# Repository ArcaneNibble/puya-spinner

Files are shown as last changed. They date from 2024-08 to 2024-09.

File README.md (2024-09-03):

# PY32 fidget spinner demo

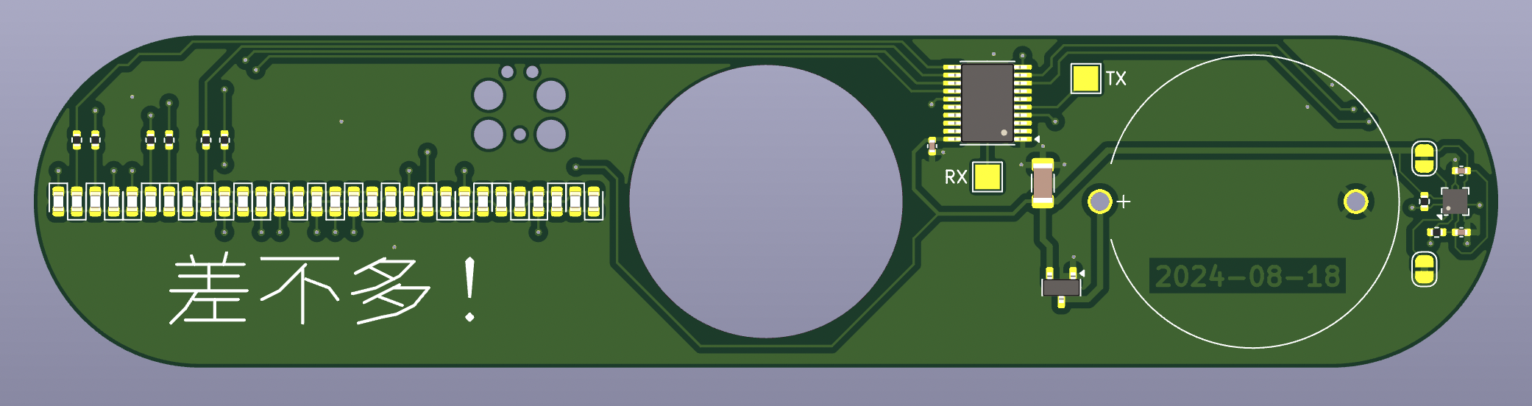
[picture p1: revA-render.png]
3d render of board


This is a quick-and-dirty demo of _just_ how cheap embedded compute can get nowadays &mdash; approximately USD$6 for an *assembled* board with a 32-bit Cortex-M0.

In order to actually make good use of this available compute, the idea was to build a modern (i.e. state-space) control theory estimator to determine the orientation of the fidget spinner from accelerometer data, rather than more traditional approaches involving hall effect sensors.

## Status

Revision A was ordered from JLCPCB, and all of the essential components work.

The state estimator has yet to be written, as the author is aphantasic and not much of a shape rotator (and thus struggling with writing out the necessary "physical world" equations).

## Main components

* PY32F002AL15 (MCU)
* SC7A20 (accelerometer)
* CR2032 battery
* 30 charlieplexed LEDs

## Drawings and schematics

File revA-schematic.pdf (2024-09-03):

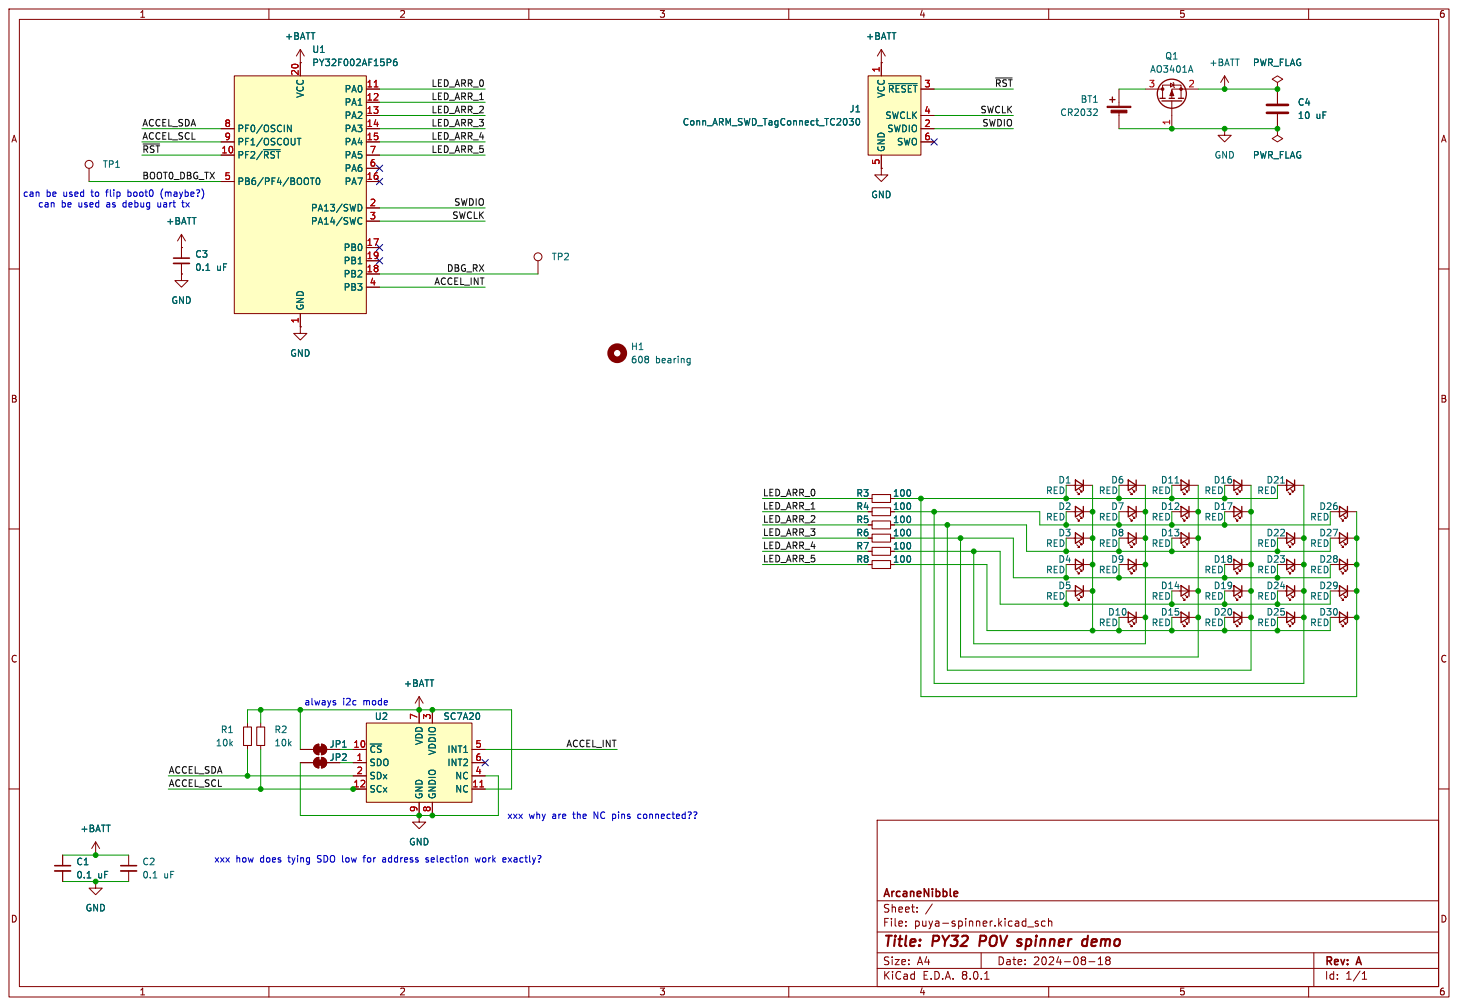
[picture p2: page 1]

1 PF2/~{RST} 10 PA0 11 PA1 12 PA2 13 PA3 14 PA4 15 PA7 16 PB0 17 PB2 18 PB1 19 PA13/SWD 2 VCC 20 PA14/SWC 3 PB3 4 PB6/PF4/BOOT0 5 PA6 6 PA5 7 PF0/OSCIN 8 PF1/OSCOUT 9 U1PY32F002AF15P6 +BATT D29 RED

1 PF2/~{RST} 10 PA0 11 PA1 12 PA2 13 PA3 14 PA4 15 PA7 16 PB0 17 PB2 18 PB1 19 PA13/SWD 2 VCC 20 PA14/SWC 3 PB3 4 PB6/PF4/BOOT0 5 PA6 6 PA5 7 PF0/OSCIN 8 PF1/OSCOUT 9 GND

1 SWDIO 2 ~{RESET}3 SWCLK 4 GND

xxx why are the NC pins connected??

File: puya-spinner.kicad_sch Sheet: / ArcaneNibble GND

Id: 1/1 Title: PY32 POV spinner demo

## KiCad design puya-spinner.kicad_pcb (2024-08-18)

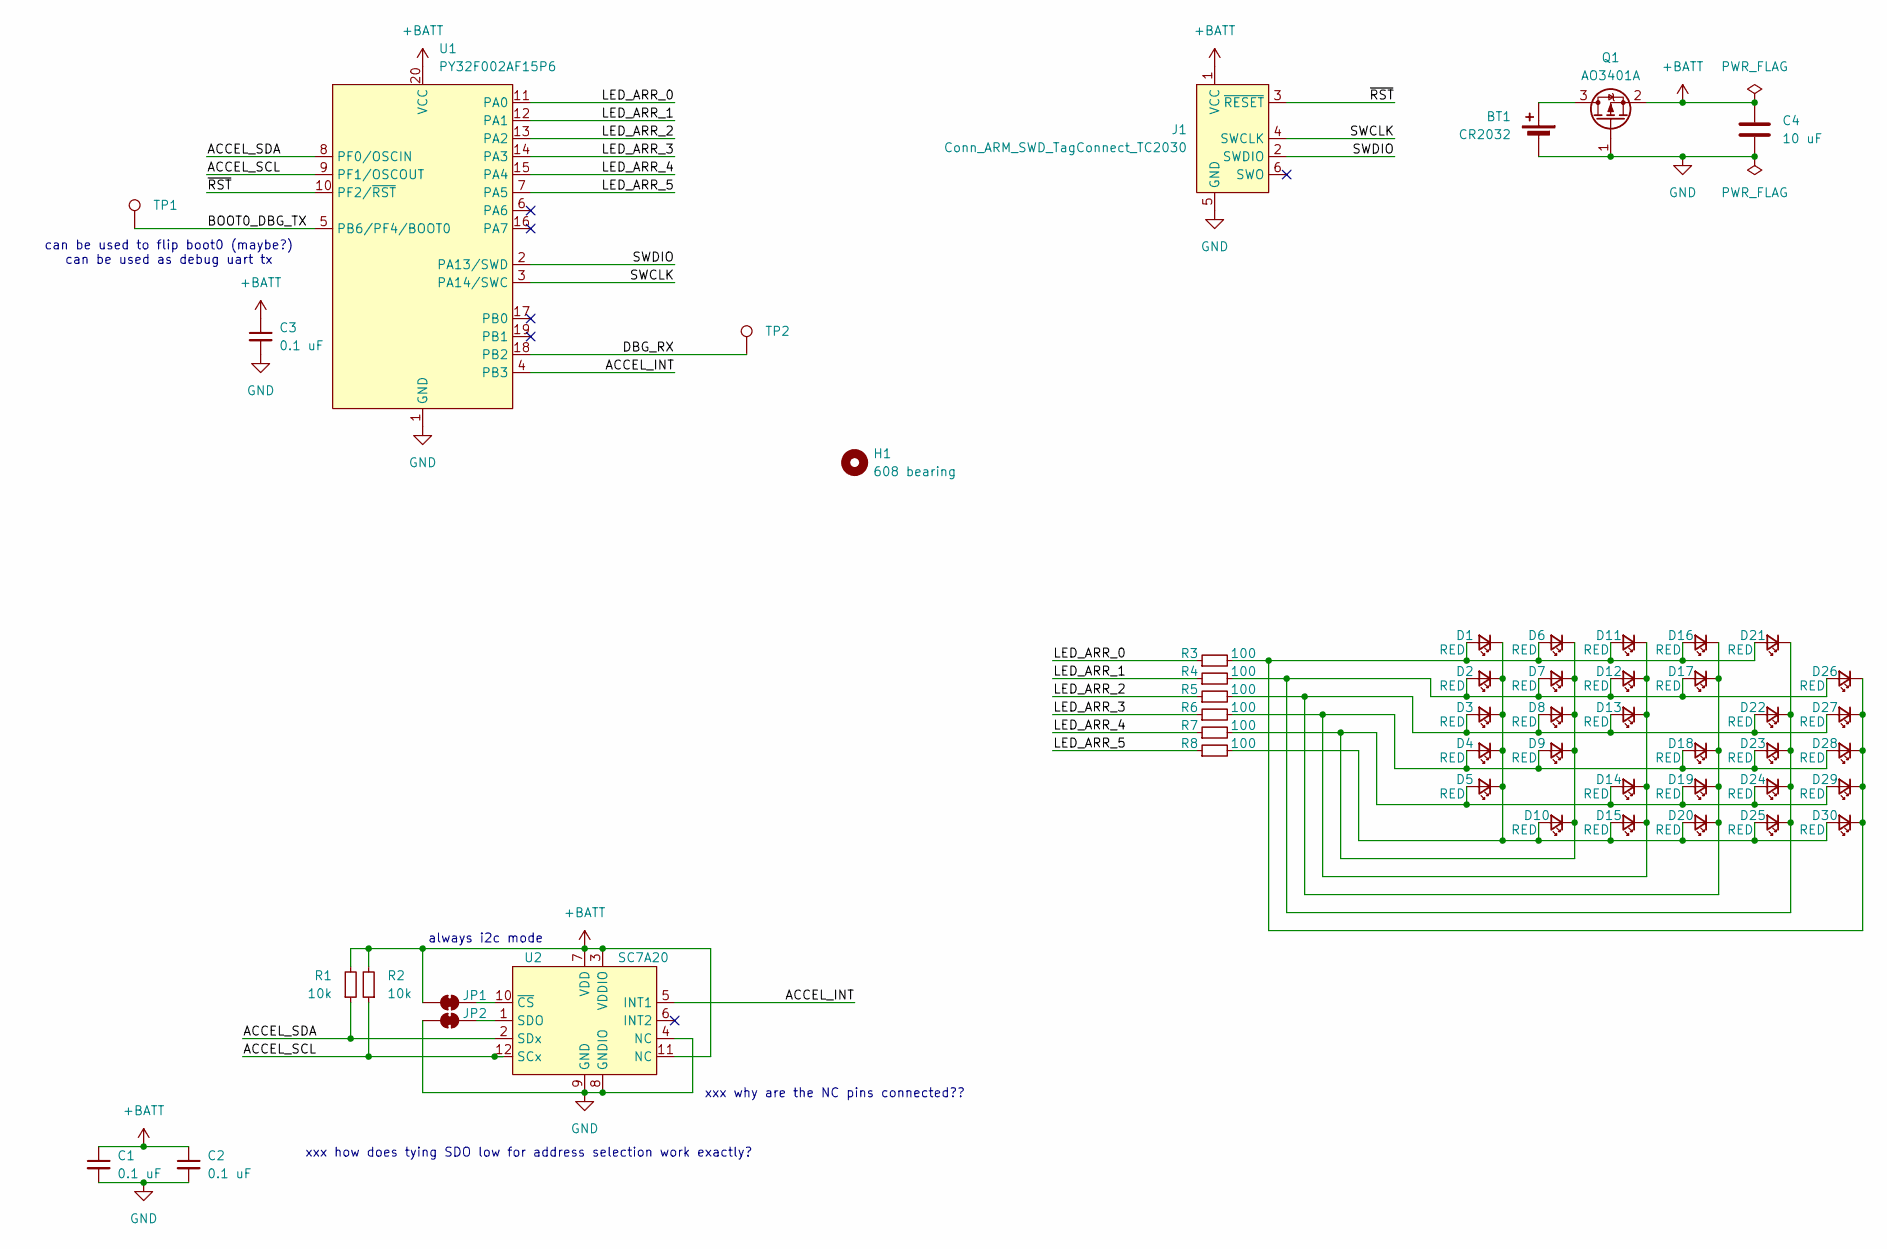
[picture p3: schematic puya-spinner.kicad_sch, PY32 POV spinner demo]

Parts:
BT1: CR2032; Battery_MYOUNG_BS-07-A1BJ001_CR2032; LCSC C2979167
C1, C2, C3: 0.1 uF; C_0402_1005Metric; LCSC C1525
C4: 10 uF; C_1206_3216Metric; LCSC C13585
D1, D2, D3, D4, D5, D6, D7, D8, D9, D10, D11, D12, D13, D14, D15, D16, D17, D18, D19, D20, D21, D22, D23, D24, D25, D26, D27, D28, D29, D30: RED; LED_0603_1608Metric; LCSC C2286
H1: 608 bearing; fixme_608_bearing
J1: Conn_ARM_SWD_TagConnect_TC2030; Tag-Connect_TC2030-IDC-FP_2x03_P1.27mm_Vertical
JP1, JP2: SolderJumper_2_Bridged; SolderJumper-2_P1.3mm_Bridged_RoundedPad1.0x1.5mm
Q1: AO3401A; SOT-23; LCSC C15127
R1, R2: 10k; R_0402_1005Metric; LCSC C25744
R3, R4, R5, R6, R7, R8: 100; R_0402_1005Metric; LCSC C25076
TP1, TP2: TestPoint; TestPoint_Pad_2.0x2.0mm
U1: PY32F002AF15P6; TSSOP-20_4.4x6.5mm_P0.65mm; LCSC C5292059
U2: SC7A20; LGA-12_2x2mm_P0.5mm; LCSC C5126709

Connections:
+BATT: C1.1, C2.1, C3.1, C4.1, J1.1 (VCC), JP1.1 (A), Q1.2 (S), R1.2, R2.2, U1.20 (VCC), U2.3 (VDDIO), U2.7 (VDD), U2.11 (NC)
/ACCEL_INT: U1.4 (PB3), U2.5 (INT1)
/ACCEL_SCL: R2.1, U1.9 (PF1/OSCOUT), U2.12 (SCx)
/ACCEL_SDA: R1.1, U1.8 (PF0/OSCIN), U2.2 (SDx)
/BOOT0_DBG_TX: TP1.1, U1.5 (PB6/PF4/BOOT0)
/DBG_RX: TP2.1, U1.18 (PB2)
/LED_ARR_0: R3.1, U1.11 (PA0)
/LED_ARR_1: R4.1, U1.12 (PA1)
/LED_ARR_2: R5.1, U1.13 (PA2)
/LED_ARR_3: R6.1, U1.14 (PA3)
/LED_ARR_4: R7.1, U1.15 (PA4)
/LED_ARR_5: R8.1, U1.7 (PA5)
/SWCLK: J1.4 (SWCLK), U1.3 (PA14/SWC)
/SWDIO: J1.2 (SWDIO), U1.2 (PA13/SWD)
/~RST: J1.3 (~RESET), U1.10 (PF2/~RST)
GND: BT1.2 (-), C1.2, C2.2, C3.2, C4.2, J1.5 (GND), JP2.1 (A), Q1.1 (G), U1.1 (GND), U2.4 (NC), U2.8 (GNDIO), U2.9 (GND)
unnamed: BT1.1 (+), Q1.3 (D)
unnamed: D1.2 (A), D6.2 (A), D11.2 (A), D16.2 (A), D21.2 (A), D26.1 (K), D27.1 (K), D28.1 (K), D29.1 (K), D30.1 (K), R3.2
unnamed: D1.1 (K), D2.1 (K), D3.1 (K), D4.1 (K), D5.1 (K), D10.2 (A), D15.2 (A), D20.2 (A), D25.2 (A), D30.2 (A), R8.2
unnamed: D5.2 (A), D6.1 (K), D7.1 (K), D8.1 (K), D9.1 (K), D10.1 (K), D14.2 (A), D19.2 (A), D24.2 (A), D29.2 (A), R7.2
unnamed: D4.2 (A), D9.2 (A), D11.1 (K), D12.1 (K), D13.1 (K), D14.1 (K), D15.1 (K), D18.2 (A), D23.2 (A), D28.2 (A), R6.2
unnamed: D2.2 (A), D7.2 (A), D12.2 (A), D17.2 (A), D21.1 (K), D22.1 (K), D23.1 (K), D24.1 (K), D25.1 (K), D26.2 (A), R4.2
unnamed: D3.2 (A), D8.2 (A), D13.2 (A), D16.1 (K), D17.1 (K), D18.1 (K), D19.1 (K), D20.1 (K), D22.2 (A), D27.2 (A), R5.2
unnamed: JP1.2 (B), U2.10 (~CS)
unnamed: JP2.2 (B), U2.1 (SDO)

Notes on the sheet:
always i2c mode
can be used to flip boot0 (maybe?) can be used as debug uart tx
xxx how does tying SDO low for address selection work exactly?
xxx why are the NC pins connected??

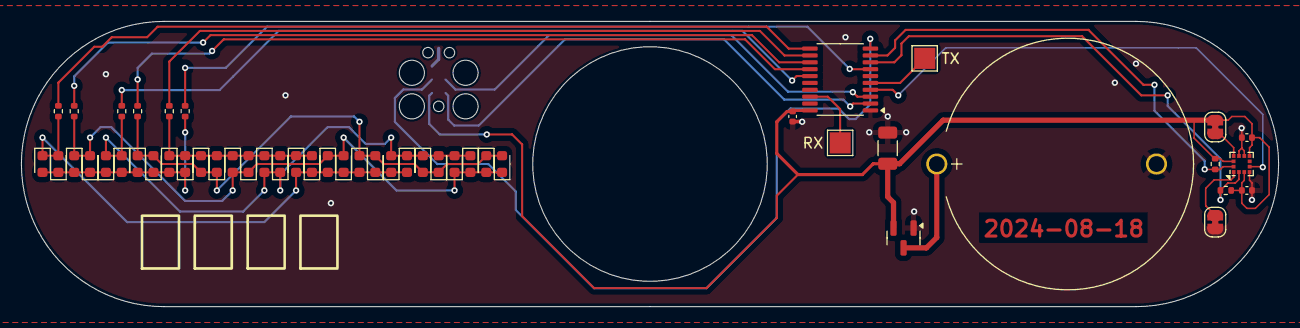
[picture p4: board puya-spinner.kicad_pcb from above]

Board: 2 copper layers, 119.0 x 27.0 mm, 52 parts (1 on the bottom side), 25 nets.

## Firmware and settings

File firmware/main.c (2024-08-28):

#include "registers.h"
#include "accel.h"
#include "led.h"
#include <math.h>

uint8_t debug_accel_whoami;
uint8_t debug_accel_ctrl_readback[6];
#define DEBUG_BUF_NENTS     1200
int16_t debug_accel_buffer[DEBUG_BUF_NENTS];
uint32_t debug_accel_buffer_idx;

void main() {
    /// 24 MHz HSI
    RCC_ICSCR = RCC_ICSCR & 0xffff0000 | (4 << 13) | CAL_HSI_24M;

    /// GPIO power on
    RCC_IOPENR = 0b100011;

    /// I2C setup
    RCC_APBENR1 |= (1 << 21);
    // 24 MHz system clock
    I2C_CR2 = 24;
    // 400 kHz I2C
    I2C_CCR = (1 << 15) | 20;
    I2C_TRISE = 8;
    // enable
    I2C_CR1 = 1;
    // gpio
    GPIOF_OTYPER = 0b11;
    GPIOF_OSPEEDR = 0b1010;
    GPIOF_AFRL = 0xcc;
    GPIOF_MODER = (GPIOF_MODER & ~0b1111) | 0b1010;

    /// Accel setup
    debug_accel_whoami = accel_read_reg(0x0f);
    accel_write_reg(0x20, 0b01110111);
    accel_write_reg(0x21, 0b00000000);
    accel_write_reg(0x22, 0b00010000);
    accel_write_reg(0x23, 0b00001000);
    accel_write_reg(0x24, 0b00000000);
    accel_write_reg(0x25, 0b00000000);
    accel_read_multi_reg(0x20, 6, debug_accel_ctrl_readback);

    /// xxx dummy data
    for (int i = 0; i < NUM_SECTORS; i++) {
        led_data[i] = (1 << (i % (NUM_LEDS + 1))) - 1;
    }

    /// systick setup, 24 kHz = 30 LEDs * 400 Hz * 2x doubling
    SYST_CVR = 0;
    SYST_RVR = 999;
    SYST_CSR = 0b111;

    /// PB3 = accel interrupt
    GPIOB_MODER &= ~(0b11 << 6);
    EXTI_EXTICR1 = 0b01 << 24;
    EXTI_RTSR = 1 << 3;
    EXTI_IMR |= 1 << 3;
    NVIC_IPR1 = 0xc0 << 16;     // lower prio than led

    // initial read to make sure interrupt pin is cleared
    while (!(GPIOB_IDR & (1 << 3))) {}
    uint8_t dummy_accel_buf[7];
    accel_read_multi_reg(0x27, 7, dummy_accel_buf);

    /// final interrupt enable
    NVIC_ISER = 1 << 6;
    
    while (1)
        asm volatile("wfi");
}

void EXTI2_3_IRQHandler() {
    EXTI_PR = 1 << 3;
    uint8_t accel_buf[7];
    accel_read_multi_reg(0x27, 7, accel_buf);

    int16_t x = accel_buf[1] | (accel_buf[2] << 8);
    int16_t y = accel_buf[3] | (accel_buf[4] << 8);
    int16_t z = accel_buf[5] | (accel_buf[6] << 8);

    debug_accel_buffer[debug_accel_buffer_idx++] = x;
    debug_accel_buffer[debug_accel_buffer_idx++] = y;
    debug_accel_buffer[debug_accel_buffer_idx++] = z;
    if (debug_accel_buffer_idx == DEBUG_BUF_NENTS)
        debug_accel_buffer_idx = 0;

    // maths!
    float angle = atan2f(-y, x);
    float led_sector_f = angle * ((float)(NUM_SECTORS / 2) / (float)(M_PI));
    int led_sector = floorf(led_sector_f);
    if (led_sector < 0)
        led_sector += NUM_SECTORS;
    led_current_sector = led_sector;
}

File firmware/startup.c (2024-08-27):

extern unsigned int _etext;
extern unsigned int _data;
extern unsigned int _edata;
extern unsigned int _bss;
extern unsigned int _ebss;
extern char _eusrstack;

extern void (*__preinit_array_start []) ();
extern void (*__preinit_array_end []) ();
extern void (*__init_array_start []) ();
extern void (*__init_array_end []) ();
extern void (*__fini_array_start []) ();
extern void (*__fini_array_end []) ();

extern void main();
void _start() {
    unsigned int *src, *dst;

    // copy initialized data
    src = &_etext;
    dst = &_data;
    while (dst < &_edata)
        *dst++ = *src++;
    
    // clear bss
    dst = &_bss;
    while (dst < &_ebss)
        *dst++ = 0;
    
    // init functions
    void (**fn)();

    fn = __preinit_array_start;
    while (fn != __preinit_array_end)
        (*fn++)();
    fn = __init_array_start;
    while (fn != __init_array_end)
        (*fn++)();

    // finally invoke main
    main();

    // fini functions
    fn = __fini_array_start;
    while (fn != __fini_array_end)
        (*fn++)();

    // hang
    while (1) {}
}

#define DUMMY __attribute__ ((weak, alias ("__irq_handler_dummy")))
void __irq_handler_dummy()
{
  	while (1);
}

DUMMY void NMI_Handler();
DUMMY void HardFault_Handler();
DUMMY void SVC_Handler();
DUMMY void PendSV_Handler();
DUMMY void SysTick_Handler();
DUMMY void WWDG_IRQHandler();
DUMMY void PVD_IRQHandler();
DUMMY void RTC_IRQHandler();
DUMMY void FLASH_IRQHandler();
DUMMY void RCC_IRQHandler();
DUMMY void EXTI0_1_IRQHandler();
DUMMY void EXTI2_3_IRQHandler();
DUMMY void EXTI4_15_IRQHandler();
DUMMY void DMA1_Channel1_IRQHandler();
DUMMY void DMA1_Channel2_3_IRQHandler();
DUMMY void ADC_COMP_IRQHandler();
DUMMY void TIM1_BRK_UP_TRG_COM_IRQHandler();
DUMMY void TIM1_CC_IRQHandler();
DUMMY void TIM3_IRQHandler();
DUMMY void LPTIM1_IRQHandler();
DUMMY void TIM14_IRQHandler();
DUMMY void TIM16_IRQHandler();
DUMMY void TIM17_IRQHandler();
DUMMY void I2C1_IRQHandler();
DUMMY void SPI1_IRQHandler();
DUMMY void SPI2_IRQHandler();
DUMMY void USART1_IRQHandler();
DUMMY void USART2_IRQHandler();
DUMMY void LED_IRQHandler();

__attribute__ ((used, section(".vectors")))
void (* const __vectors[])() =
{
    (void (*const)())&_eusrstack,
    _start,
    NMI_Handler,
    HardFault_Handler,

    0, 0, 0, 0,

    0, 0, 0,
    SVC_Handler,

    0, 0,
    PendSV_Handler,
    SysTick_Handler,

    WWDG_IRQHandler,
    PVD_IRQHandler,
    RTC_IRQHandler,
    FLASH_IRQHandler,

    RCC_IRQHandler,
    EXTI0_1_IRQHandler,
    EXTI2_3_IRQHandler,
    EXTI4_15_IRQHandler,

    0,
    DMA1_Channel1_IRQHandler,
    DMA1_Channel2_3_IRQHandler,
    0,

    ADC_COMP_IRQHandler,
    TIM1_BRK_UP_TRG_COM_IRQHandler,
    TIM1_CC_IRQHandler,
    0,

    TIM3_IRQHandler,
    LPTIM1_IRQHandler,
    0,
    TIM14_IRQHandler,

    0,
    TIM16_IRQHandler,
    TIM17_IRQHandler,
    I2C1_IRQHandler,

    0,
    SPI1_IRQHandler,
    SPI2_IRQHandler,
    USART1_IRQHandler,
    
    USART2_IRQHandler,
    0,
    LED_IRQHandler,
    0,
};

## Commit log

2024-07-09 add custom parts
    [puya-spinner.kicad_sch]
2024-07-09 initial sch
    [puya-spinner.kicad_sch]
2024-07-10 assign most parts
    [puya-spinner.kicad_sch]
2024-07-10 add power flags; fix interrupt pin
    [puya-spinner.kicad_sch]
2024-07-10 add battery holder footprint
2024-07-10 change no-connect pins
    [puya-spinner.kicad_sch]
2024-07-10 FIXME add bearing
    need to change tolerances
    [puya-spinner.kicad_sch]
2024-07-10 initial route
    [puya-spinner.kicad_pcb]
2024-07-10 tweaks; mostly to big capacitor
    [puya-spinner.kicad_pcb]
2024-07-10 mostly idle tweaks
    [puya-spinner.kicad_pcb]
2024-07-11 fix bearing hole; add reverse polarity protection
    [puya-spinner.kicad_pcb, puya-spinner.kicad_sch]
2024-07-11 some tweaks to make ground plane look nicer
    [puya-spinner.kicad_pcb]
2024-08-18 revA for fab
    [puya-spinner.kicad_pcb, puya-spinner.kicad_sch]
2024-08-27 LED data entry, chaser pattern
2024-08-28 basic i2c test
2024-08-28 interrupt-driven i2c
2024-08-28 i2c multi read maybe working
2024-08-28 fucking what hate this device
2024-08-28 accel interrupt pin works
2024-08-28 refactor out led code
